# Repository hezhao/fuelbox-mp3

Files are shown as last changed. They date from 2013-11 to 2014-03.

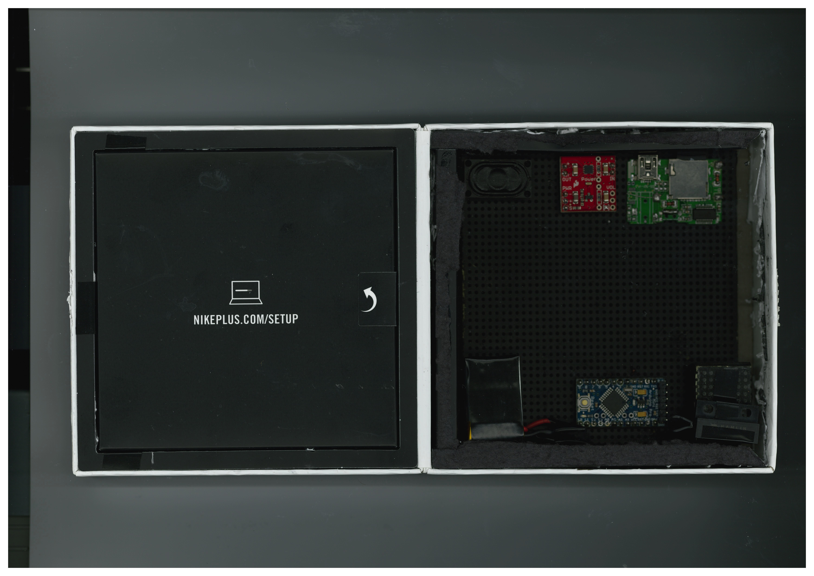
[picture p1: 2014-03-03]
v3/fuelbox_pic1.jpg

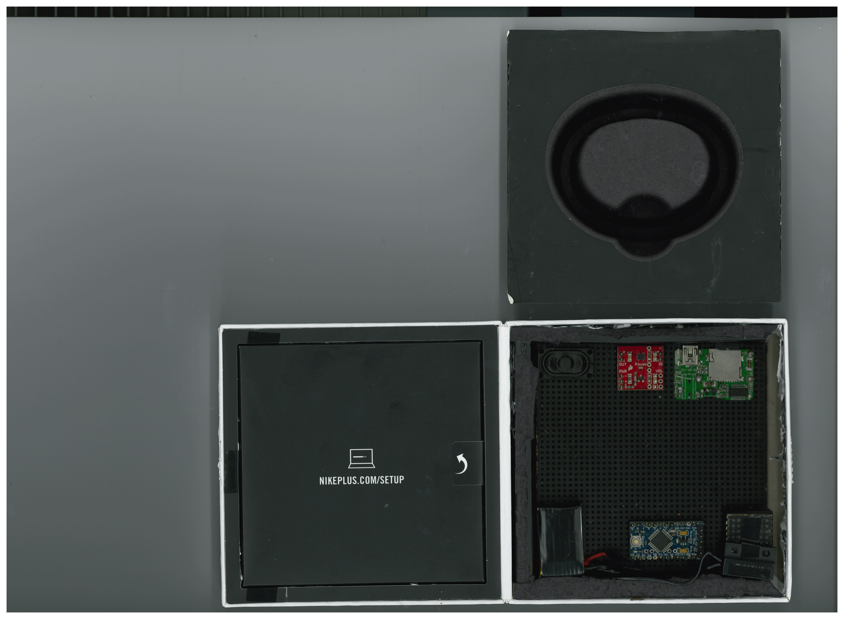
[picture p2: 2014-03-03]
v3/fuelbox_pic3.jpg

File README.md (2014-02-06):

Fuelbox MP3
===========

prototype
circuit

* v1v2: An mp3 player controller board with LM386 op-amp, using touch sensor, push button and light sensor as trigger.
* v3: An mp3 player + Arduino + TPA2005D1 amp all-in-one triggered only by SPST-NC reed switch (SPDT will do too, just choose NC pair). Once triggered, Arduino checks the EEPROM flag, plays the audio once, and sleeps forever.

Power Consumption
=================
* Arduino Pro Mini 5V + MP3 module + TPA2005D1 amp = 50mA @ 7.4V
* Arduino Pro Mini 5V = 15mA @ 5V
* TPA2005D1 = 15mA @ 5V
* Sleep Mode: Arduino Pro Mini 5V = 0.58mA @ 9V
* Sleep Mode: TPA2005D1 = 0.5µA @ 5V (datasheet)
* Limits: 2032 Battery max discharge = 10mA @ 3V
* Limits: Arduino digital pin max output current = 40mA
* Limits: Arduino VCC-GNC max output current = 200mA

Notes
=====
* When using LiPo battery, there is a large inrust current. A 30Ω current limiting resistor is placed in serial with reed switch. However, limiting resistor is not necessary with for TPA2005D1
* <del> R = U / Switching Current = 7.4V / 0.25A = 29.6Ω; For absolute safety, use R = 8.2V / 0.25A = 32.8Ω since fully charged LiPo battery can reach 4.2V </del>
* TPA2005D1 amp produces a short bust sound if triggered by the arduino digital pin, so instead it is directly powered by VCC and digital pin 9 shutsdown amp after audio finishes

TODO
====
* v2: TOUCH sensor is not supposed to be grounded (GND plane may cause problem)
* v2: Remove vias that connect to TOUCH sensor

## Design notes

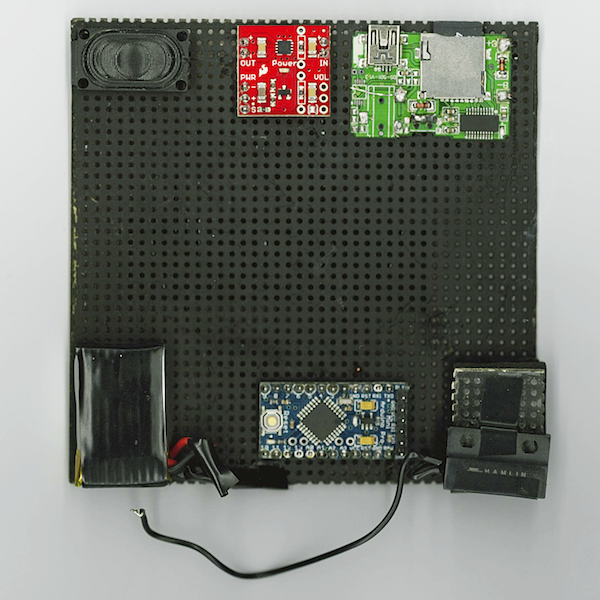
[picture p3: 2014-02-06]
v3/prototype.png

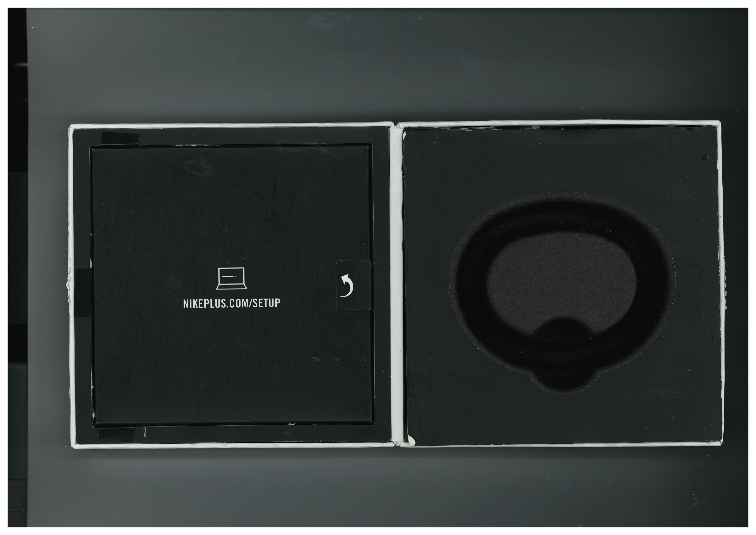
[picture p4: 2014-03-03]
v3/fuelbox_pic2.jpg

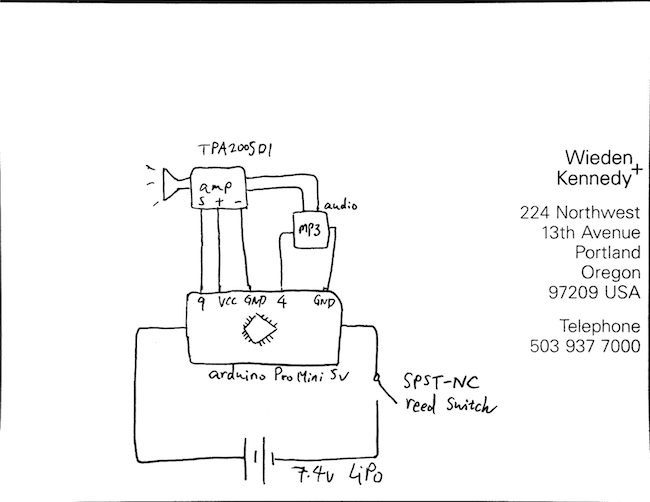
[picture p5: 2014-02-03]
v3/circuit.png

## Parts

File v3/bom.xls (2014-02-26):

BOM
Item | Unit Price | QTY | Total | URL
PCB | $7.17 | 0.5 | $3.58 | http://www.dipmicro.com/store/PCB-UNI30
Trimpot 10k | $0.37 | 1 | $0.37 | http://www.dipmicro.com/store/R3296W-103
Aruduno Pro Mini 328 - 5V | $8.96 | 1 | $8.96 | https://www.sparkfun.com/products/11113
Audio amplifier module | $7.16 | 1 | $7.16 | https://www.sparkfun.com/products/11044
LiPo Battery 7.4V 180mAh | $2.90 | 1 | $2.90 | http://www.valuehobby.com/power-systems/batteries/2s-lipo/gforce-20c-180mah-2s-eflite-micro-umx.html
mini MP3 player | $5.99 | 1 | $5.99 | http://www.ebay.com/itm/161106817940
Micro SD card 4GB | $5.70 | 1 | $5.70 | http://www.ebay.com/itm/190722461527
CUI 8 ohm speaker | $5.52 | 1 | $5.52 | GC0251K-ND (DigiKey)
SPST-NC Reed switch | $4.07 | 1 | $4.07 | 59140-040-ND (DigiKey)
Resistor 33 Ohm 1/4W | $0.03 | 1 | $0.03 | CF14JT33R0CT-ND (DigiKey)
Resistor 10K Ohm 1/4W | $0.03 | 1 | $0.03 | CF14JT10K0CT-ND (DigiKey)
Magnets | $2.99 | 0.2 | $0.60 | http://www.harborfreight.com/10-piece-rare-earth-magnets-67488.html
Total |  |  | $44.91

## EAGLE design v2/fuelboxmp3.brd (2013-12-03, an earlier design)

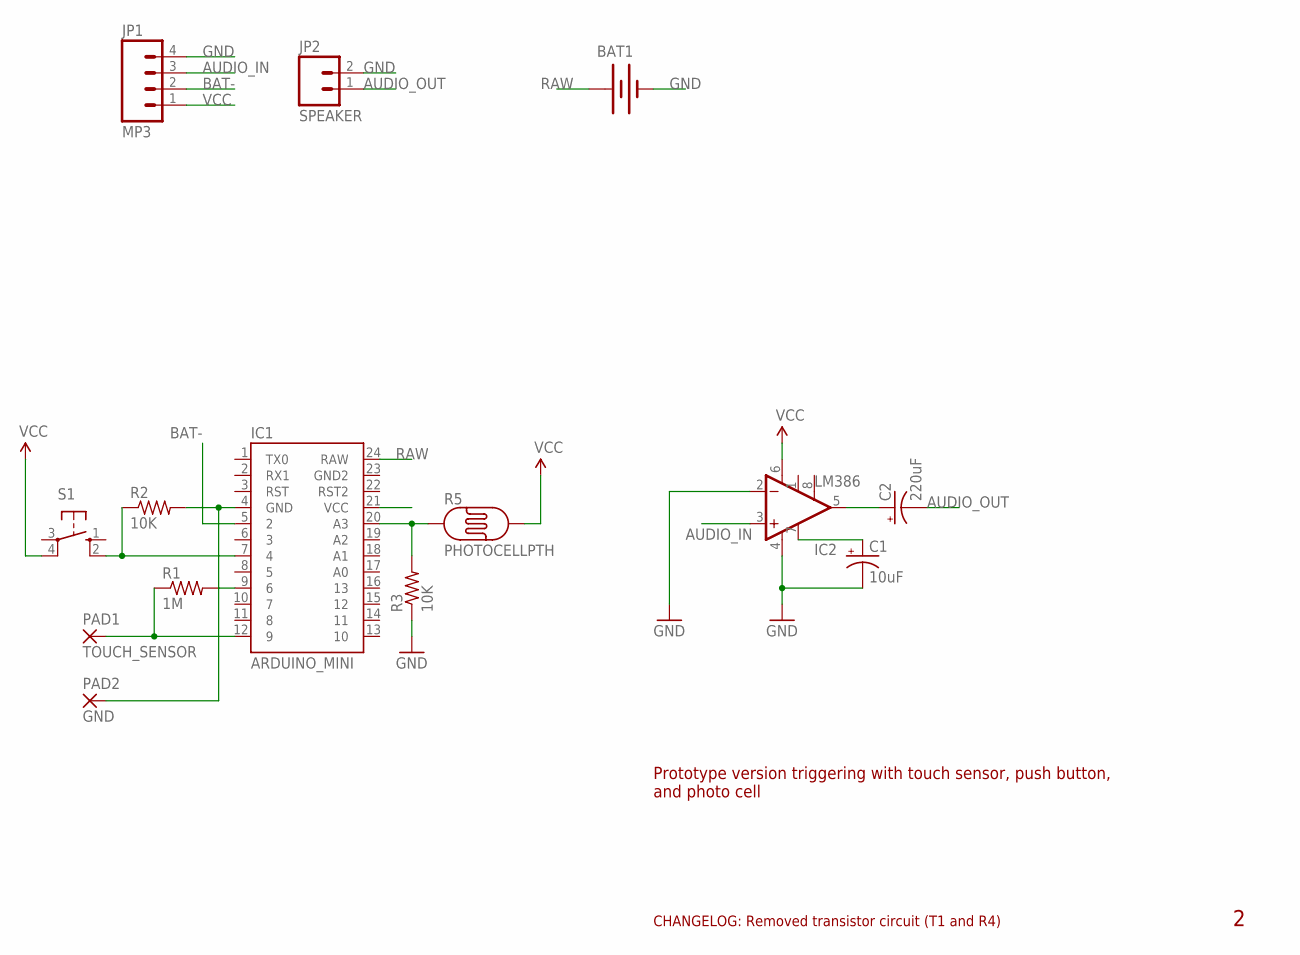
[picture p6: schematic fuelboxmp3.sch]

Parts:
BAT1: BATTERY1100; LIPO-1100MAH
C1: 10uF; E2,5-5
C2: 220uF; E2,5-6
IC1: ARDUINO_MINI
IC2: LM386; DIP08
JP1: MP3; 1X04
JP2: SPEAKER; 1X02
PAD1: TOUCH_SENSOR; 3,81/1,1
PAD2: GND; 3,81/1,1
R1: 1M; 0204/7
R2, R3: 10K; 0204/7
R5: PHOTOCELLPTH; PHOTOCELL
S1: 10-XX; B3F-10XX

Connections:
AUDIO_IN: IC2.3 (+IN), JP1.3
AUDIO_OUT: C2.-, JP2.1
BAT-: IC1.5 (2), JP1.2
GND: BAT1.-, C1.-, IC1.4 (GND), IC2.2 (-IN), IC2.4 (V-), JP1.4, JP2.2, PAD2.1, R2.2, R3.1
unnamed: IC1.9 (6), R1.2
unnamed: IC1.12 (9), PAD1.1, R1.1
unnamed: C2.+, IC2.5 (OUT)
unnamed: IC1.7 (4), R2.1, S1.2 (S1)
unnamed: IC1.20 (A3), R3.2, R5.1
unnamed: C1.+, IC2.7 (BP)
RAW: BAT1.+, IC1.24 (RAW)
VCC: IC1.21 (VCC), IC2.6 (V+), JP1.1, R5.2, S1.4 (P1)

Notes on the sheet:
Prototype version triggering with touch sensor, push button, and photo cell
CHANGELOG: Removed transistor circuit (T1 and R4)

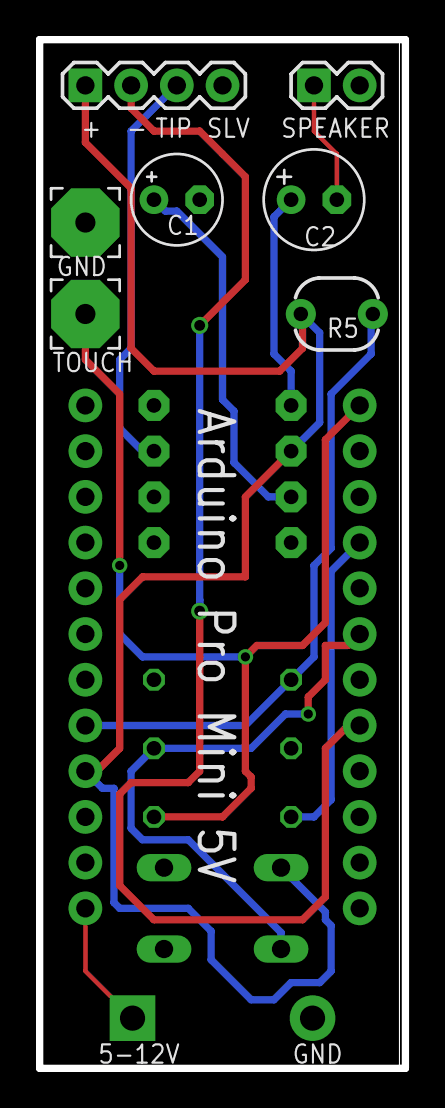
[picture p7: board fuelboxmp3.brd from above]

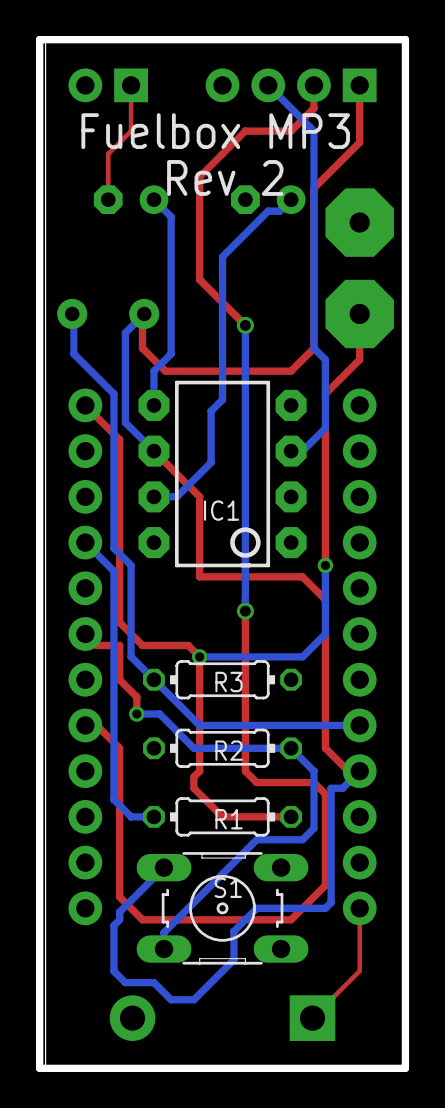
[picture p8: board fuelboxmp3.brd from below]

Board: 2 copper layers, 20.3 x 57.1 mm, 14 parts (5 on the bottom side), 12 nets.

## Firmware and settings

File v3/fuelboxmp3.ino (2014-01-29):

/*
 * TODO
 * - Perf board (dipmicro.com & radioshack)
 * - Digikey reed switch (WebID 50506821, Access ID 14620)
 *
 * See http://playground.arduino.cc/Learning/arduinoSleepCode
 *
 * Wakes up for 10 seconds, sends HIGH to mp3Pin, and then sleeps 
 * forever, in sleep mode, arduino Pro Mini 5V consumes 0.58mA on a 
 * 9V battery.
 *
 * Uncomment code for interrupt wake up upon pin2 going LOW. Use a
 * pull-up 10K resistor between VCC and pin2. When pin2 goes LOW
 * it activates INT0 external interrupt, bringing the MCU back to life.
 */

#include <EEPROM.h>
#include <avr/sleep.h>

const int addr           = 209;    // EEPROM address to store flag
const int audioDuration  = 10;     // audio duration in seconds

//const int wakePin = 2;           // interrupt pin to wake up arduino
const int mp3Pin         = 4;      // pin that sources power to mp3 player
const int ampShutdownPin = 9;      // TPA2005D1 audio amplifier SDN pin (<0.8V off, >2V on)
const int ledPin         = 13;     // led indicator

void setup()
{
//    Serial.begin(9600);
    //  pinMode(wakePin, INPUT);
    pinMode(mp3Pin, OUTPUT);
    pinMode(ampShutdownPin, OUTPUT);
    pinMode(ledPin, OUTPUT);
    //  attachInterrupt(0, wakeUpNow, LOW);
    play();
}

void loop()
{
    sleepNow();
    delay(100);
}

void EEPROMReset()
{
    // Locations that have never been written to have the value of 255
    for (int i = 0; i < 512; i++) {
        EEPROM.write(i, 255);
    }
}

int EEPROMCheck()
{
    bool shouldPlay = false;
    
    int val = EEPROM.read(addr);
//    Serial.print("val: ");
//    Serial.println(val);
    
    // start counter if addr has never been written
    if (val >= 255) {
        val == 0;
    }
    
    // play every other time
    if (val % 2 == 0) {
        shouldPlay = true;
    }
    
    EEPROM.write(addr, ++val);
    return shouldPlay;
}

void wakeUpNow()        // here the interrupt is handled after wakeup
{
    // execute code here after wake-up before returning to the loop() function
    // timers and code using timers (serial.print and more...) will not work here.
    // we don't really need to execute any special functions here, since we
    // just want the thing to wake up
}

void play()
{
    if (EEPROMCheck() == false) 
    {
        return;
    }
    
    int count = 0;
    while (count < audioDuration)
    {
        digitalWrite(mp3Pin, HIGH);
        digitalWrite(ampShutdownPin, HIGH);
        digitalWrite(ledPin, HIGH);
        delay(500);
        digitalWrite(ledPin, LOW);
        delay(500);
        count++;
//        Serial.print("playing: ");
//        Serial.println(count);
    }
    
    // Entering Sleep mode after 10 seconds
    if (count >= audioDuration)
    {
        digitalWrite(mp3Pin, LOW);
        digitalWrite(ampShutdownPin, LOW);
        digitalWrite(ledPin, LOW);
        // this delay is needed, the sleep function will provoke a Serial error otherwise!!
        delay(100);
    }
}

void sleepNow()
{
    set_sleep_mode(SLEEP_MODE_PWR_DOWN);   // sleep mode is set here
    sleep_enable();          // enables the sleep bit in the mcucr register
    // so sleep is possible. just a safety pin
    //    attachInterrupt(0, wakeUpNow, LOW); // use interrupt 0 (pin 2) and run function
    // wakeUpNow when pin 2 gets LOW
    sleep_mode();            // here the device is actually put to sleep!!
    // THE PROGRAM CONTINUES FROM HERE AFTER WAKING UP
    sleep_disable();         // first thing after waking from sleep:
    // disable sleep...
    //    detachInterrupt(0);      // disables interrupt 0 on pin 2 so the
    // wakeUpNow code will not be executed
    // during normal running time.
}

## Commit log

2013-11-04 submitted to OSH Park
    [fuelboxmp3.brd]
2013-12-03 add arduino code v2
2013-12-03 version 2: removed transistor circuit T1 and R4 because BAT- was GND when open. BAT- now connects directly to Pin 2
    [fuelboxmp3.brd, fuelboxmp3.sch]
2014-01-23 version 3 no pcb
2014-01-27 use audioPin = 4, add circuit drawing
2014-01-29 use sparkfun TPA2005D1 amp, use pin 9 as shutdown pin
2014-02-03 update circuit diagram
2014-02-06 add prototype picture
2014-02-06 delte prototype.png
2014-02-06 add prototype.png back
2014-02-26 added bom
    [bom.xls]

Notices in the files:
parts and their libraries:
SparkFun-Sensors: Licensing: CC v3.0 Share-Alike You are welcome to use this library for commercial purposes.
